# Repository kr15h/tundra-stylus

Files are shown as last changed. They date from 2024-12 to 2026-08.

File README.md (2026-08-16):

# Tundra Stylus

> This project has migrated. See [Lighthouse Stylus](https://gitlab.com/kriwkrow/lighthouse-stylus).

Tundra Tracker stylus baseplate for 3D positional tracking. This repository contains design files and test application source code. It currently works with [SteamVR](https://store.steampowered.com/app/250820/SteamVR/), but [libsurvive](https://github.com/cntools/libsurvive) support is on its way.

https://github.com/user-attachments/assets/fd64adfa-e3c0-4b6a-a956-ca7f262a2909

## Introduction

Vive Lighthouse system is great! The main use of it is VR, but what about drawing or painting in space? Stylus input is the natural choice of many, but there is no VIVE Lighthouse Stylus available. Logitech almost launched VR Ink, but then decided not to. What to do?

[Tundra Tracker](https://tundra-labs.com/products/additional-tracker) is the smallest available off-the-shelve tracker that is compatible with the VIVE Lighthouse system. It offers a great deal of flexibility via its [IO Expansion Board](https://tundra-labs.com/products/tundra-tracker-io-expansion-board). With that in mind, all we need is a neat circuit board with buttons and a 3D-printable structure that looks and feels like a stylus. 

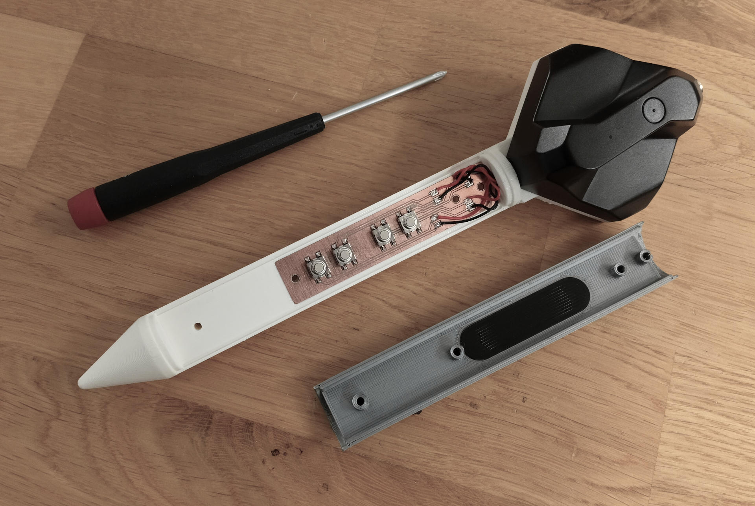
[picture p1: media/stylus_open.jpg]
Stylus Open


And that is Tundra Stylus! Produce the circuit board, 3D print the enclosure and you are ready to go, given that you have the Tundra Tracker and its IO Expansion board.

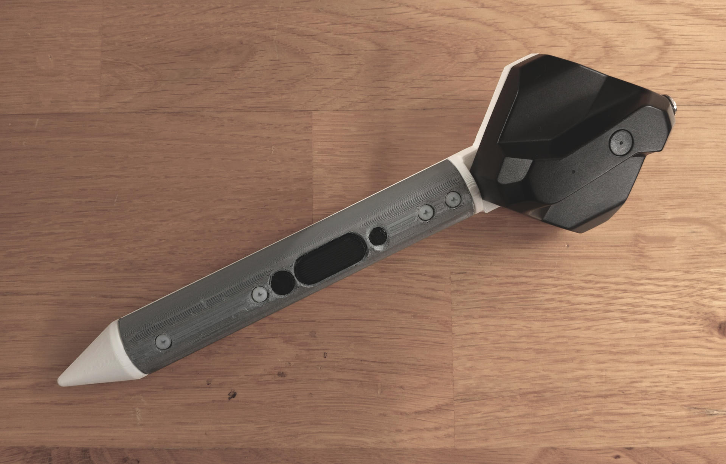
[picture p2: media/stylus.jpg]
Stylus


## Getting Started

Here is a table of contents of different documentation sections that will tell you what to do. You can also jump right to the design, electronics and software sections if you know all that by heart and prefer not to read too much documentation. It is up to you.

- [BOM](docs/BOM.md)  
  Start here as you will need to purchase some things to get started.
- [PCB Production](docs/PCB_PRODUCTION.md)  
  This may take time too so better start early.
- [3D Printing](docs/3D_PRINTING.md)  
  This one is relatively fast, given you have FDM printer available.
- [Assembly](docs/ASSEMBLY.md)  
  Putting it all together should be not hard, given you have all the parts (and tools).
- [Usage](docs/USAGE.md)  
  The setup and software part of the process.
- [Contributing](docs/CONTRIBUTING.md)  
  You are willing to improve something? Great!

## License

This repository contains multiple components, each licensed under different terms. Please review the specific license for each component below.

1. The CAD files in this repository are licensed under the **Creative Commons Attribution-NonCommercial 4.0 International (CC BY-NC 4.0)**.
2. The electronics design files in this repository are licensed under the **Creative Commons Attribution-NonCommercial 4.0 International (CC BY-NC 4.0)**.
3. The source code in this repository is licensed under the **MIT License**.

Please consult [LICENSE.md](LICENSE.md) for more detail.

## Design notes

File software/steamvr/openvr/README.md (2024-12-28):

# SteamVR OpenVR proxy

This proxy uses Python OpenVR bindings to extract tracking data from SteamVR.

## Dependencies

- [SteamVR](https://store.steampowered.com/app/250820/SteamVR/) with null driver enabled
- [websocketd](http://websocketd.com/)
- [Python 3.6](https://www.python.org/) with [openvr](https://github.com/cmbruns/pyopenvr?tab=readme-ov-file)

## Usage

Make sure you start SteamVR and that the Tundra Tracker attached to the stylus is detected. The following will make the websocket server available at `ws://localhost:8080/`.

```
websocketd --address=localhost --port=8080 python proxy.py
```

If you want to debug, you probably would like to enable verbose output.

```
python proxy.py -v
```

You can also display help if you want.

```
python proxy.py -h
```

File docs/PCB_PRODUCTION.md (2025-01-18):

# PCB Production

An essential component of the Tundra Stylus is its button board with 4 tactile switches. 

Tundra Stylus PCB

There are four cable pairs connecting the pads on the board with the Tundra Stylus IO Expansion board that is placed under the Tundra Stylus itself.

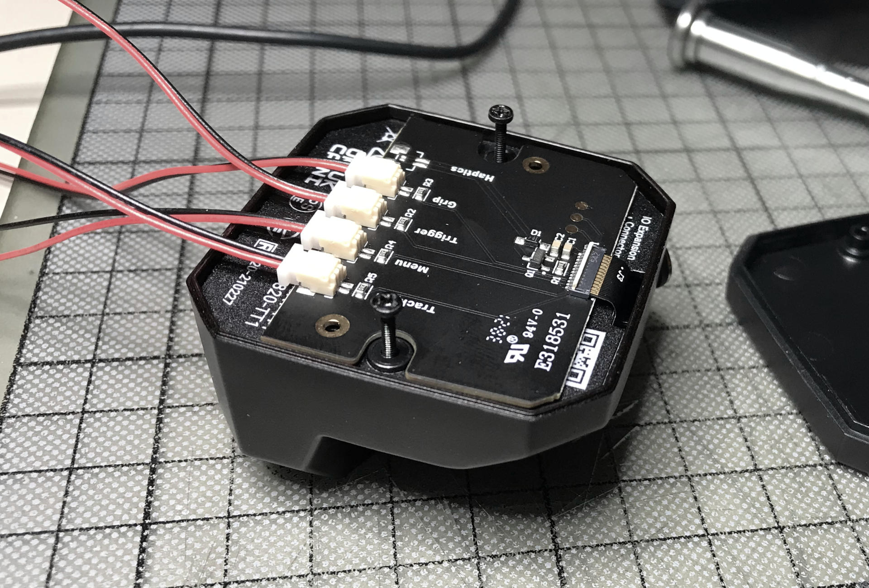
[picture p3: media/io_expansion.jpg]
IO Expansion Board


The cables are connected to the PCB in the following order (starting from the tip of the stylus upward).

1. Trigger
2. Grip
3. Trackpad
4. Menu

The names of the buttons might make you think that some of them can sense pressure, but all of them are plain digital IO buttons. You will need to cut them shorter, but try to leave a bit of extra in case you mess something up.

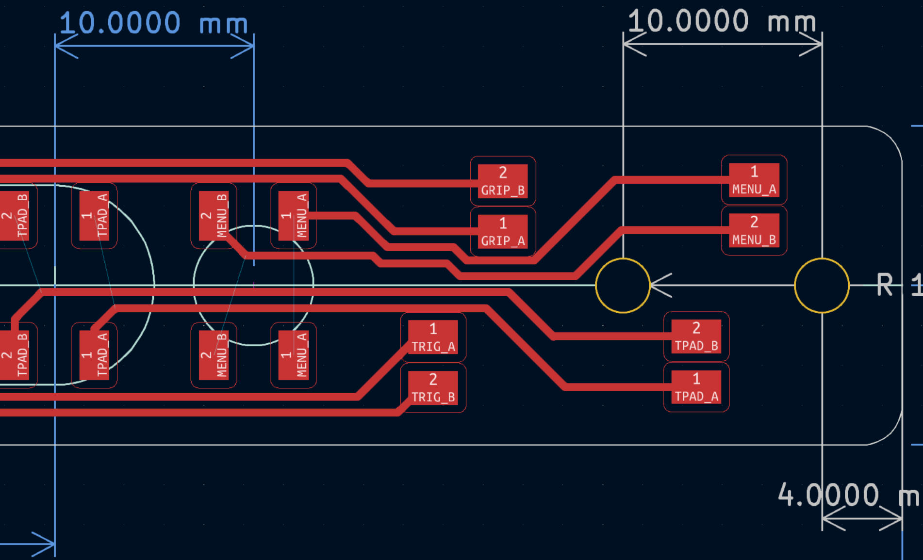
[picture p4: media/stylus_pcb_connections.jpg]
Stylus PCB Connections


## Making the Board

There are two ways to make the board.

1. PCB milling
2. Manufacturing online

### PCB Milling

Gerber files for PCB milling process can be found in [electronics/gerbers/milling](../electronics/gerbers/milling) directory. You can use KiCad electronics design software to export Gerber files for manufacturing online. KiCad 7 was used to design the board.

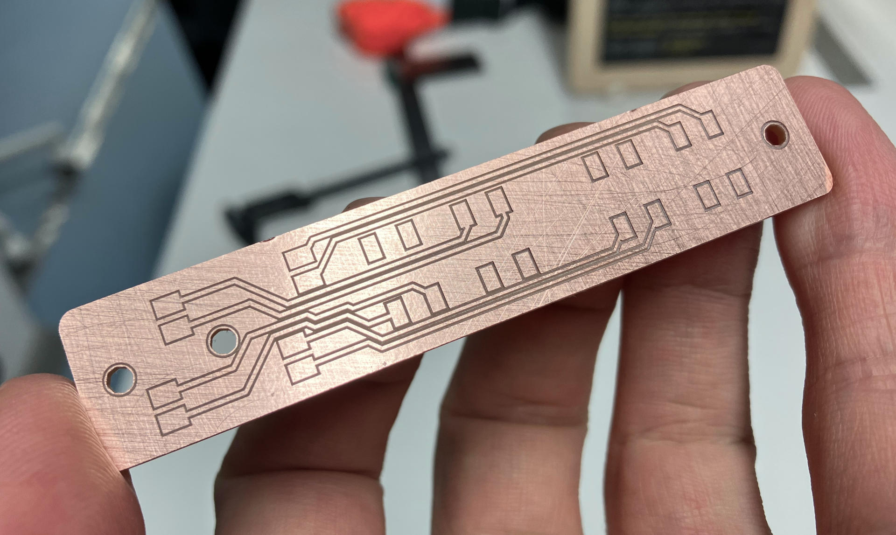
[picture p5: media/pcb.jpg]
Plain PCB


As for the milling process, CopperCAM software was used to calculate toolpaths in HPGL form. Then, Bungard CCD/2 MTC machine was used to mill the board. A 60deg V bit was used for isolation milling and a 0.8mm cylindrical tool was used to cut the holes and outline. FR2 single-sided copper clads from Bungard were used as the base material. 

### Manufacturing Online

Gerber files for manufacturing a single-sided board online is included in [electronics/gerbers/online](../electronics/gerbers/online). It has been tested with JLCPCB and PCBWay. It should show up as in the images below. 

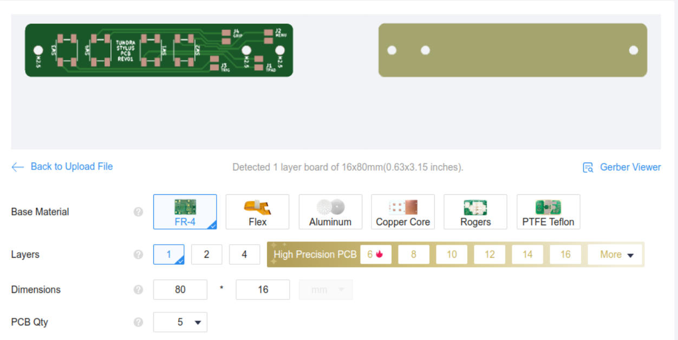
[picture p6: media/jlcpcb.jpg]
JLCPCB


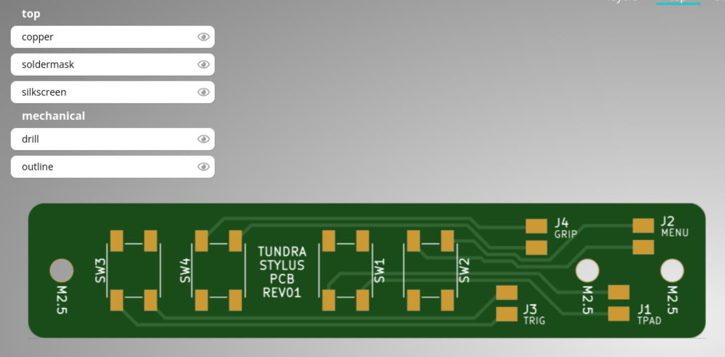
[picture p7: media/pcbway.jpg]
PcbWAY


As for the parameters, the following are most important.

| Parameter | Value |
| --- | --- |
| Base Material | FR-4 |
| Layers | 1 |
| PCB Thickness | 1.6mm |

Do not forget to order a SMT-Stencil if you want to use solder paste and reflow soldering. 

Below is a photo of how the board should look like when ordered via JLCPCB.

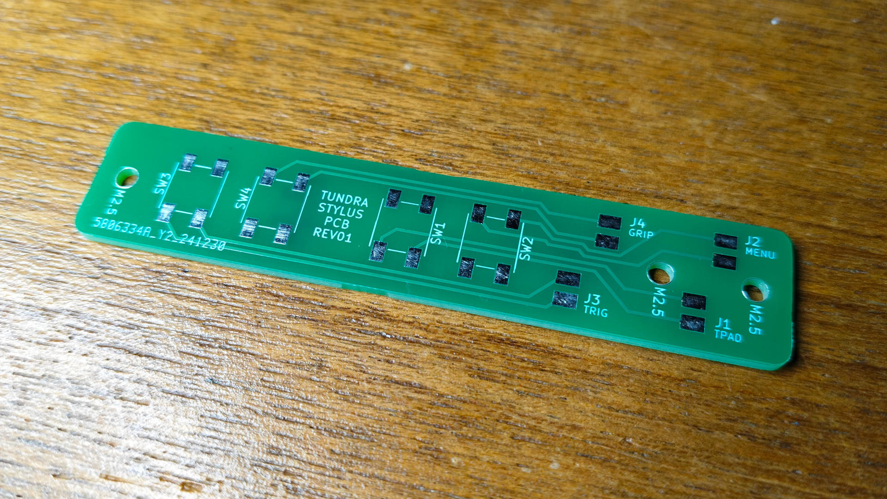
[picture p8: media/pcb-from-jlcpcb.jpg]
Photo of Tundra Stylus PCB from JLCPCB


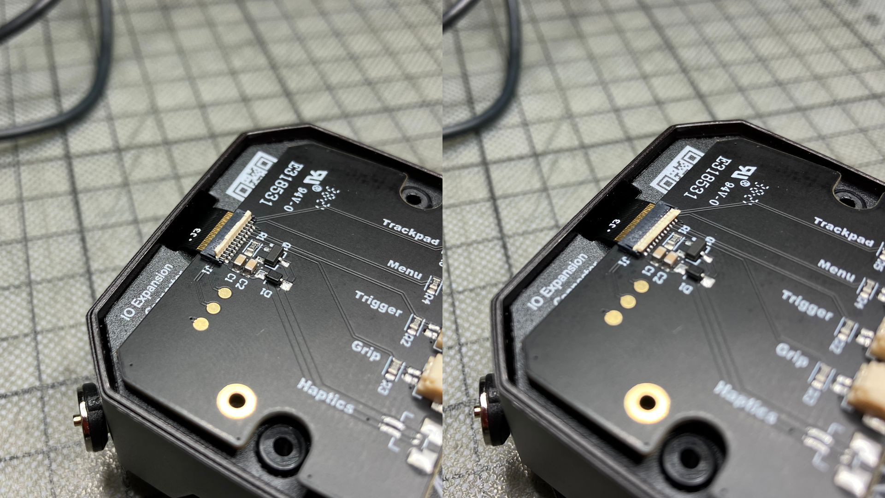
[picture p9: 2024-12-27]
media/tundra-io-ribbon.jpg

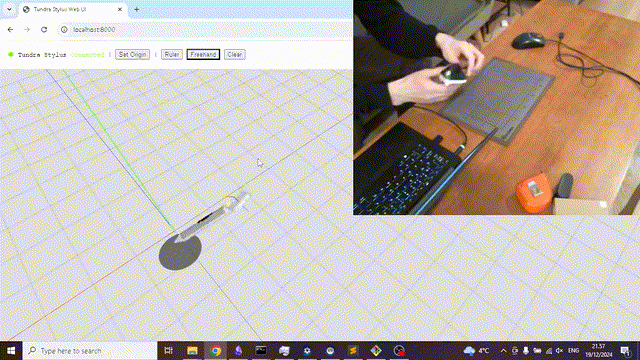
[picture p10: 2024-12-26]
media/hello.gif

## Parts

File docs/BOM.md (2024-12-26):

# BOM

Tundra Stylus would not be possible without a list of core off-the-shelve components. 

- [Tundra Tracker](https://tundra-labs.com/products/additional-tracker)
- [Tundra Tracker IO Expansion Board](https://tundra-labs.com/products/tundra-tracker-io-expansion-board)
- [VIVE Base Station](https://www.vive.com/us/accessory/base-station2/) (2pcs is optimal, but you can get up to 4 for ultra fidelity tracking)

## Tools

- 3D printer. I used Prusa MK4.
- PCB milling machine. I used Bungard CCD/2 MTC.
- Soldering station.
- Screwdriver.

## Parts

| Description | Amount | Link |
| --- | --- | --- |
| PLA Filament[^1] | 320g[^2] | [3DK Berlin](https://3dk.berlin/en/pla/109-pla-filament-milky-white.html) |
| FR2 single-sided copper clad at least 100x20mm[^3] | 1pcs | [Bungard](https://www.bungard.de/en/consumables/consumables/special-purpose-laminates)[^4] |
| Nylon bolts, M2.5, 20mm | 4pcs | [DigiKey](https://www.digikey.fi/en/products/detail/essentra-components/50M025045D020/11637988) |
| Nylon Nuts, M2.5 | 4pcs | [DigiKey](https://www.digikey.fi/en/products/detail/essentra-components/04M025045HN/9677099) |
| Tactile switch, Omron, B3SN-3112P | 4pcs | [DigiKey](https://www.digikey.com/en/products/detail/omron-electronics-inc-emc-div/B3SN-3112P/27856) |

[^1]: It is up to you what PLA type and manufacturer you choose. I printed with filament from 3dk.berlin on Prusa MK4 printers at the Aalto Fablab.

[^2]: The weight here is the avaiable spool size as it would be probably hard to purchase an exact amount.

[^3]: This is if you choose to do PCB milling at a fablab. Of course you can use FR4, but it is at your own risk. 

[^4]: Bungard is the manuacturer and you should contact them to find out distributors in your country.

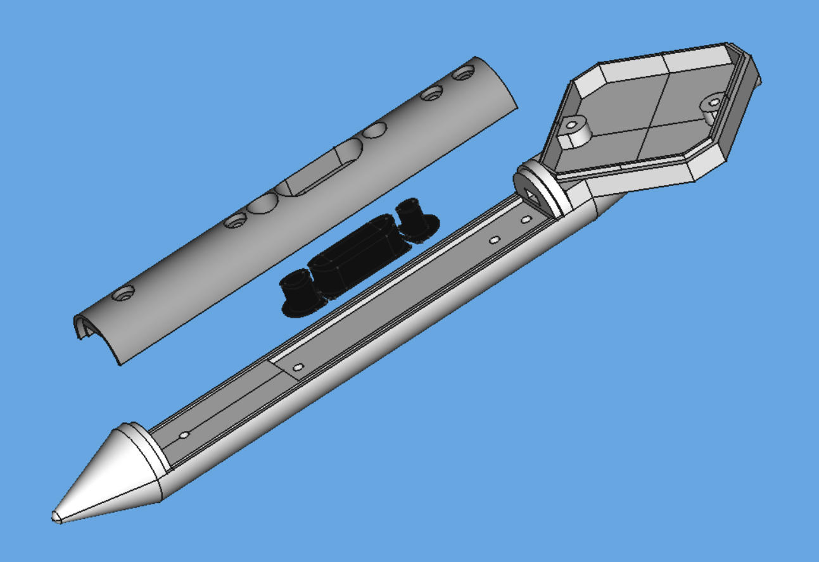
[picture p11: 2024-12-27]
media/design_parts.jpg

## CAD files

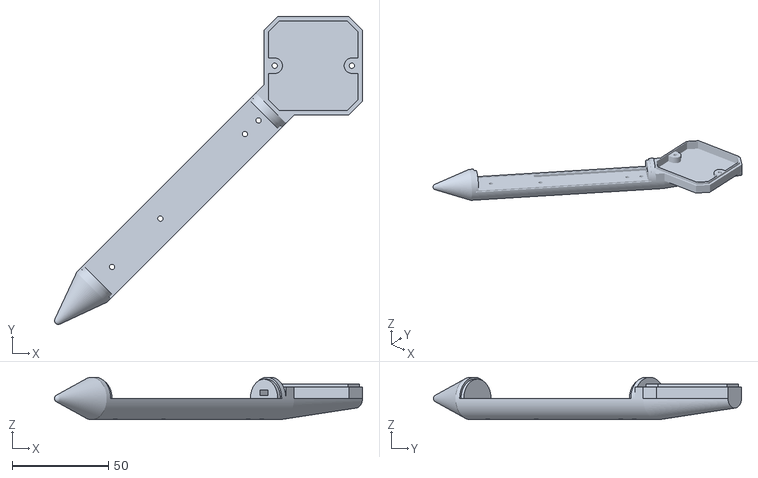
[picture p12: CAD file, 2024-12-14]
design/3dprint/TundraStylus_Rev01-Baseplate.stl
159.6 x 159.6 x 22.0

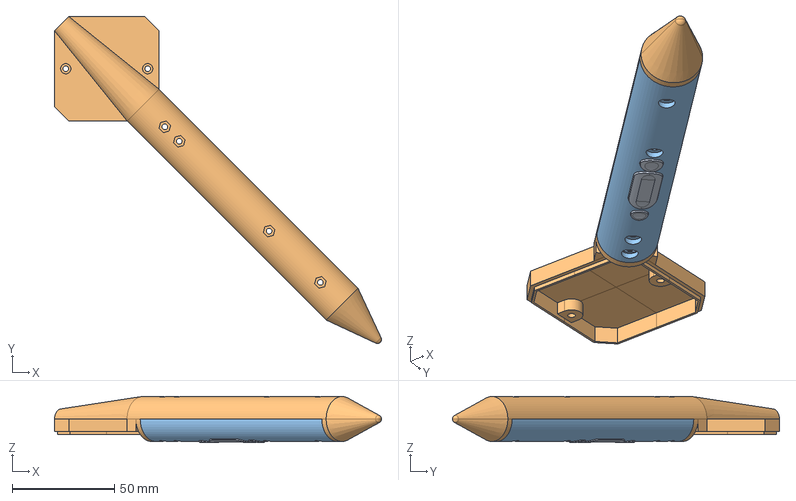
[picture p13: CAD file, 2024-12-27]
design/freecad/TundraStylus_Rev01.FCStd
159.6 x 159.6 x 22.5 mm
ButtonInlay
Baseplate
Cover

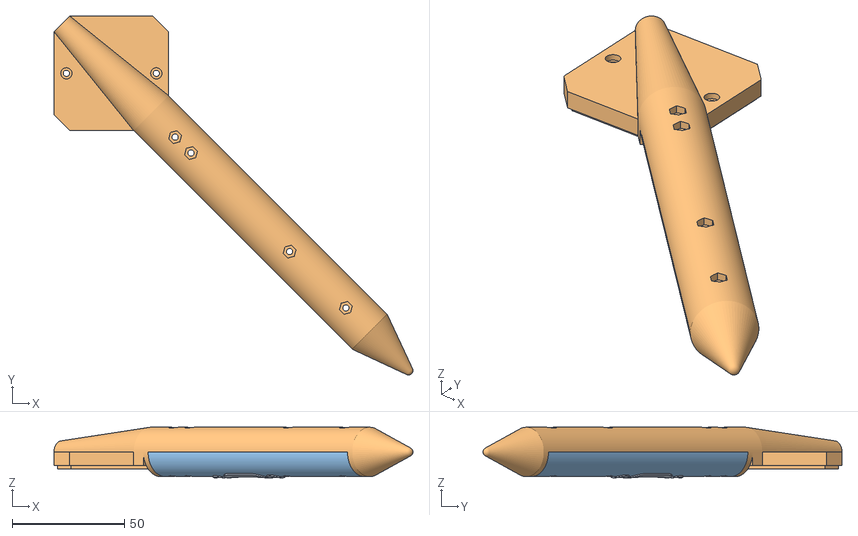
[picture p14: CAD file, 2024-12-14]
software/webui/assets/models/tundrastylus.obj
159.6 x 159.6 x 22.5
Buttons Final
Base Final
Cover Final

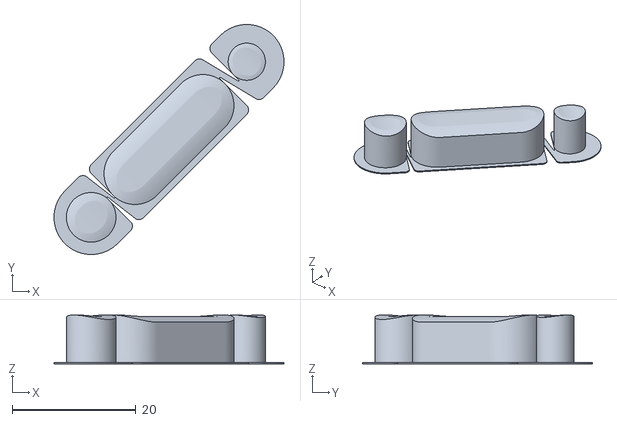
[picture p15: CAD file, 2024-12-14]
design/3dprint/TundraStylus_Rev01-ButtonInlay.stl
37.1 x 37.1 x 7.90

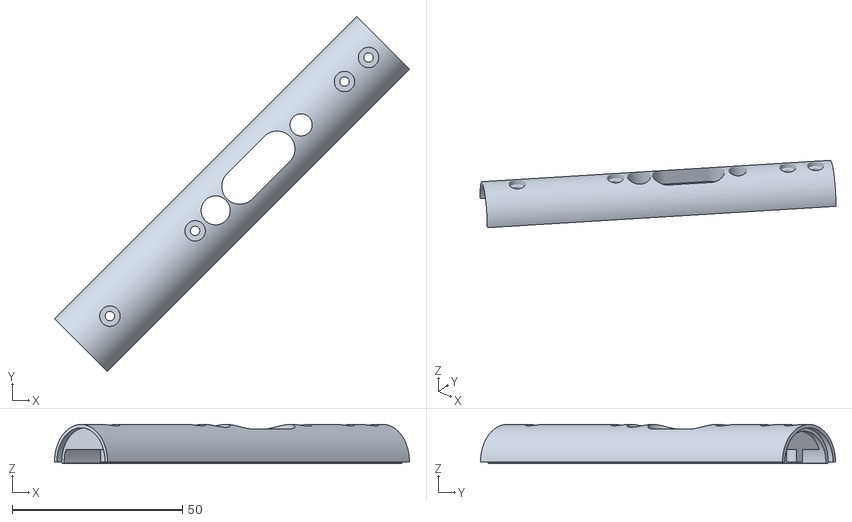
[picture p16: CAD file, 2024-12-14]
design/3dprint/TundraStylus_Rev01-Cover.stl
104.2 x 104.2 x 11.5

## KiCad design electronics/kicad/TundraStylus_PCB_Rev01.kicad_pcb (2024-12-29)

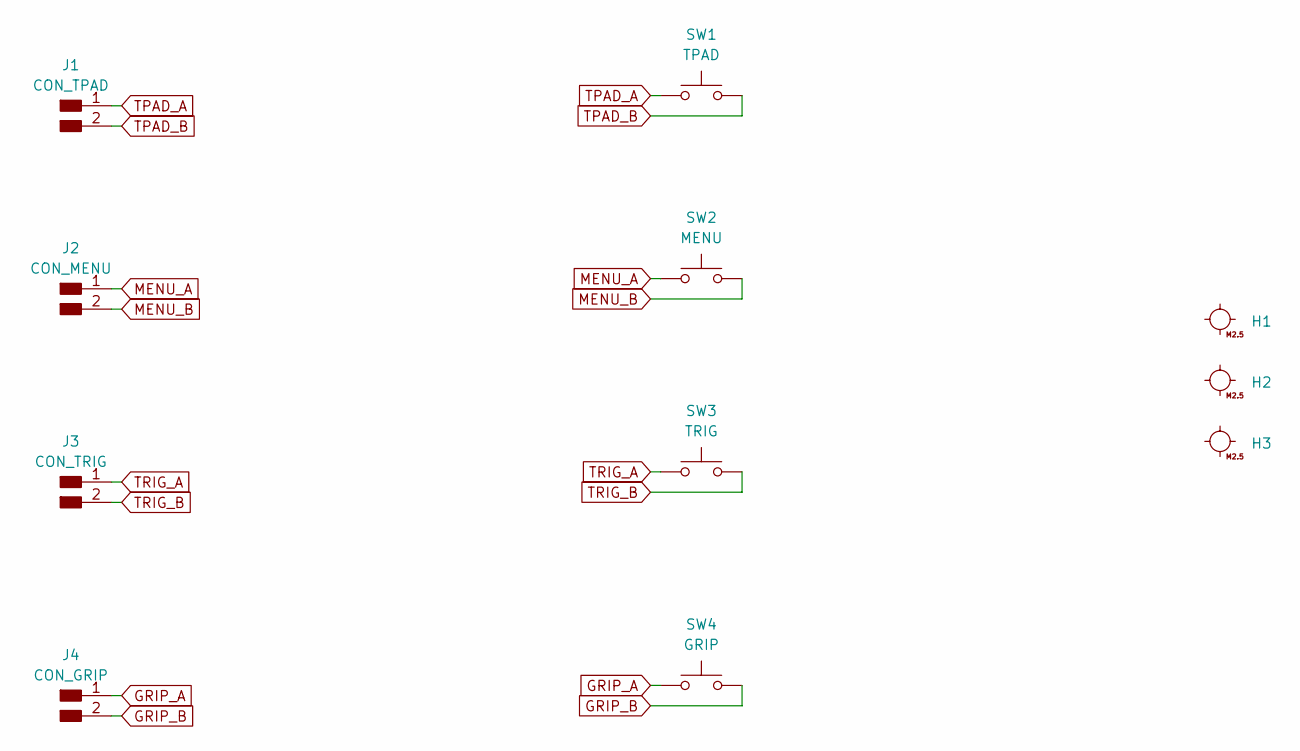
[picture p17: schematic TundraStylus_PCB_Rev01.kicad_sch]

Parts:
H1, H2, H3: MountingHole_M2.5
J1: CON_TPAD; PinHeader_1x02_P2.54mm_Horizontal_SMD
J2: CON_MENU; PinHeader_1x02_P2.54mm_Horizontal_SMD
J3: CON_TRIG; PinHeader_1x02_P2.54mm_Horizontal_SMD
J4: CON_GRIP; PinHeader_1x02_P2.54mm_Horizontal_SMD
SW1: TPAD; Button_Omron_B3SN_6.0x6.0mm
SW2: MENU; Button_Omron_B3SN_6.0x6.0mm
SW3: TRIG; Button_Omron_B3SN_6.0x6.0mm
SW4: GRIP; Button_Omron_B3SN_6.0x6.0mm

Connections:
GRIP_A: J4.1, SW4.1
GRIP_B: J4.2, SW4.2
MENU_A: J2.1, SW2.1
MENU_B: J2.2, SW2.2
TPAD_A: J1.1, SW1.1
TPAD_B: J1.2, SW1.2
TRIG_A: J3.1, SW3.1
TRIG_B: J3.2, SW3.2

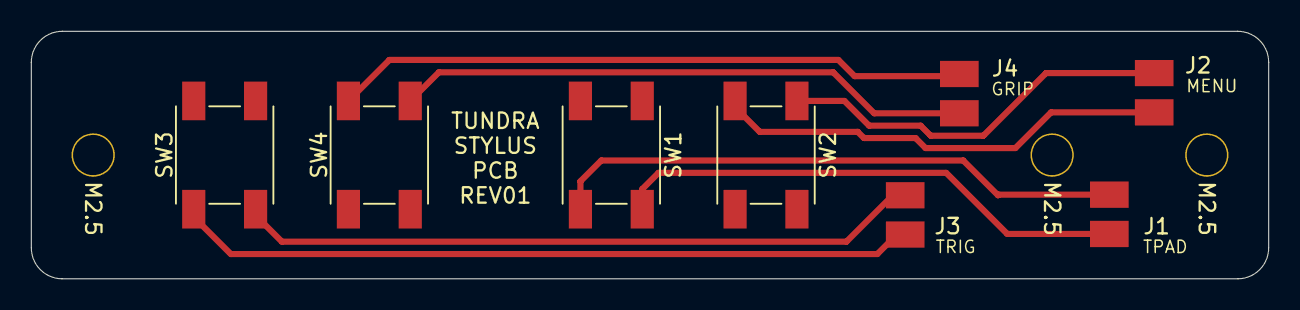
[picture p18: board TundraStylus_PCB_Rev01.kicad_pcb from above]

Board: 2 copper layers, 80.0 x 16.0 mm, 11 parts (0 on the bottom side), 8 nets.

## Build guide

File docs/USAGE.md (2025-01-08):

# Usage

Now when you have the Tundra Stylus assembled, it is time to make sure it works. You will need to set up your physical space for that first. Also make sure that your Tundra Tracker is fully charged.

## Setting up Base Stations

Tundra Stylus has been tested with Vive Base Station 2.0. One is enough, but if you want to use two or more, make sure you change the channel for one of them as in order to take advantage of multi-base-station tracking, the base stations should be on different channels. You can do this by using a pin similar to one used to remove SIM from iPhone. There is a little pin-hole on the back of the Vive Base Station, insert the pin there and press until you feel/hear a click. The base station should show up with a different channel in SteamVR now.

It is recommended to set up the base stations higher above head level, in the corners of the room. The field of view of base stations is 120deg. Tilt them a bit downward so that they cover all areas the tracker is going to reside. Also take into account the body position of yours. Set the base stations up in a way so that it is less likely that your body is going to be in the way.

## Testing in SteamVR

Once the base stations are set up, fire up your Steam software and install SteamVR. I was testing it on Windows, and got half-way on Linux, but the main reason for that was the uneven way the null driver behaves on both of the systems. 

I am using the stylus without a headset to drive cursor on screen. In order to be able to use it without headset, you will need to enable the null driver.

First, edit the default Steam VR settings and enable the "null" driver. Open the following file in a text editor and set `"enable"` to `true`.

```
C:\Program Files (x86)\Steam\steamapps\common\SteamVR\drivers\null\resources\settings\default.vrsettings
```

```json
"enable": true
```

Then, proceed to the general SteamVR settings.

```
C:\Program Files (x86)\Steam\steamapps\common\SteamVR\resources\settings\      
default.vrsettings
```

```json
"requireHmd": false,
"forcedDriver": "null",    
"activateMultipleDrivers": true
```

Restart SteamVR and turn on the tracker on the stylus. Make sure the tracker dongle included with Tundra Tracker is plugged into your computer, the VIVE base stations, and the Tundra Tracker are on. Wait for the base stations and tracker icons to show up. 

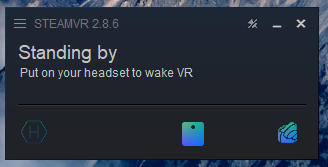
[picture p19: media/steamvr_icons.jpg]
SteamVR Icons


Next, configure your tracker as a handheld controller.

1. Select the SteamVR menu and go to Settings
2. Select Controllers
3. Select Manage Trackers
4. Set Tracker Role as Held in Hand
5. Set to Any hand (default)

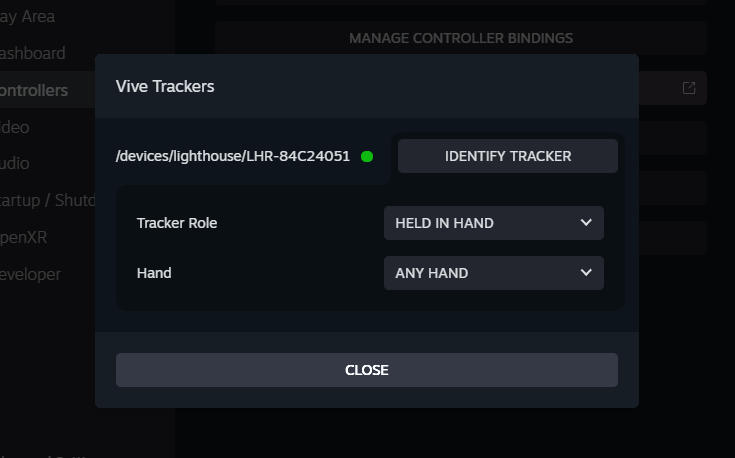
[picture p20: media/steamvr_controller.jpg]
SteamVR Controller Settings


Then open the test controller panel and test the controller.

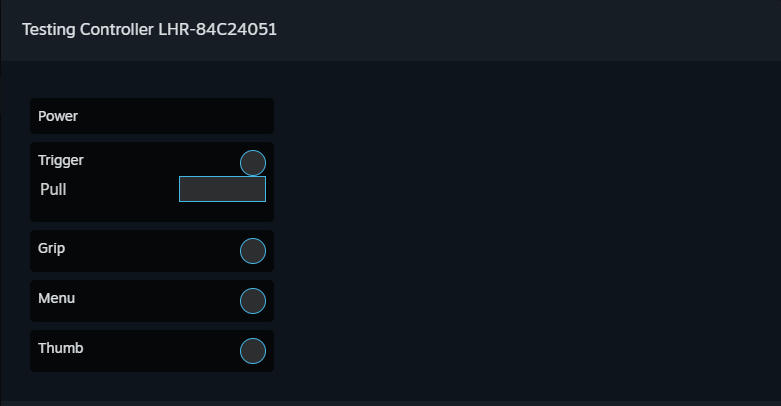
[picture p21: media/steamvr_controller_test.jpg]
SteamVR Test Controller


The circles should appear as filled as soon as you press buttons on the stylus.

https://github.com/user-attachments/assets/c7b850f1-a4ad-4b7b-adab-196a3f2940df

On Windows, you should also be able to see the Tundra Tracker floating in space via the VR View.

## Testing with Web UI

Now, that SteamVR can recognize the tracker, we can move on to application-specific adventures. The repository includes middleware, a proxy application that uses OpenVR API to communicate with SteamVR and extracts pose information that can then be passed on to any application on your computer. 

### Proxy

You can find the SteamVR compatible OpenVR proxy in the [software/steamvr](../software/steamvr/) directory. There is a README file that explains prerequisites and launching sequence. 

### Web UI

Once you get it to run, proceed to the Web UI. It is build using threejs 3D library and JavaScript modules. It requires to be launched via a local webserver. Instructions can be found in the [software/webui](../software/webui/) directory.

Open the browser and go to the address you configure your local webserver with. It will take some time for the application to start receiving tracker pose information, thus the "Waiting for Stylus" message will be there for some seconds. Once the tracker starts sending pose information, you can do several things.

1. Use the Menu button to set the origin
2. Use the Mouse to select one of two test tools
    1. Ruler tool
    2. Freehand tool
3. Use the Trigger button to place points in the case of the Ruler tool or start drawing a line with the Freehand tool.

https://github.com/user-attachments/assets/fd64adfa-e3c0-4b6a-a956-ca7f262a2909

## Creating your Own App

To build your own JavaScript application, you can reuse the `TundaStylus` class that can be found in [software/webui/js](../software/webui/js/TundraStylus.js). It follows a three step initialization.

```
// Step 1: Create sylus manager instance
const stylus = new TundraStylus();

// Step 2: Add listeners
stylus.addEventListener('new_stylus', event => { ... });
stylus.addEventListener('pose',       event => { ... });
stylus.addEventListener('click',      event => { ... });
stylus.addEventListener('pressed',    event => { ... });
stylus.addEventListener('released',   event => { ... });

// Step 3: Connect to WebSocket host
stylus.connect('ws://localhost:8080');
```

The `TundraStylus` class extends the built-in [CustomEvent](https://developer.mozilla.org/en-US/docs/Web/API/CustomEvent/CustomEvent) class. It carries data that can be accessed via `event.detail` member variable.

THe `TundraStylus` can capture and forward data of multiple styluses. As soon as first message with a specific controller ID is received, a `new_stylus` event is emited. 

The `new_stylus` event carries the ID of the newly added stylus.

```
{
    id: 1
}
```

The `pose` event carries the raw pose of the tracker, as well as the calculated tip position as `event.detail.position`.

```
{
    id,
    position,
    tracker: {
        pose,
        position,
        quaternion
    }
}
```

The `click`, `pressed` and `released` events also have a `buttonName` variable that can be one of four values: `trig`, `menu`, `grip` or `tpad`. 

```
{
    id,
    buttonName: "trig | menu | grip | tpad",
    position,
    tracker: {
        pose,
        position,
        quaternion
    }
}
```

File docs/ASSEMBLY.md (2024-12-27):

# Assembly

Given that you have soldered the tactile switches to the button PCB and processed the 3D printed parts, you are ready to proceed with the assembly process.

You will need to shorten the cables that come with the Tundra Tracker IO Expansion Board. To do that, start with connecting the cables to the expansion board. Then, open up the Tundra Tracker and insert the IO board like so.

IO Board Insertion

There are the 2x Torx T5 Thread Forming M1.6 screws missing in the image. I lost them somewhere, that is why they are not there. 

> The flat cable connector on the right has a lock mechanism. Make sure you insert the cable properly and then use a small instrument, such as tweezers, to lock it.

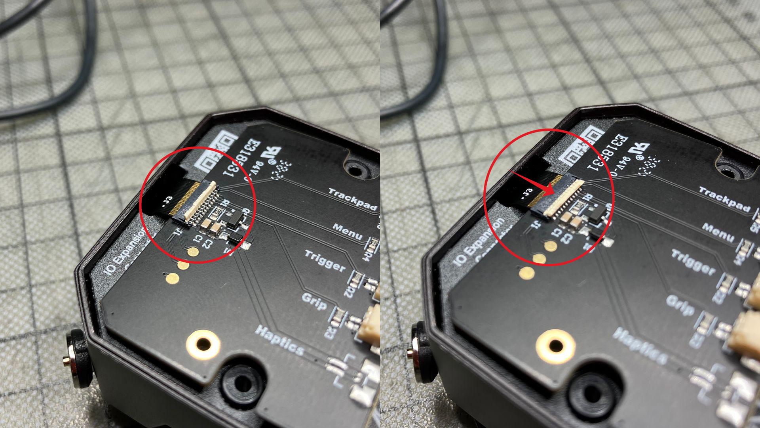
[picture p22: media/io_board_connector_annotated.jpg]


Use paper tape and label the cables as you won't be able to trace them back to the connectors on the IO board once you attach the Tundra Tracker to the Baseplate.

Then, attach the Tundra Tracker to the stylus Baseplate using the same bolts that were used to attach the original Tundra Tracker baseplate.

Guide the cables through the hole in the back of the stylus baseplate and position the circuit board. Cut the cables one-by-one, strip them, and solder them to the respective pads of the buttons. 

Tundra Stylus w/o Cover

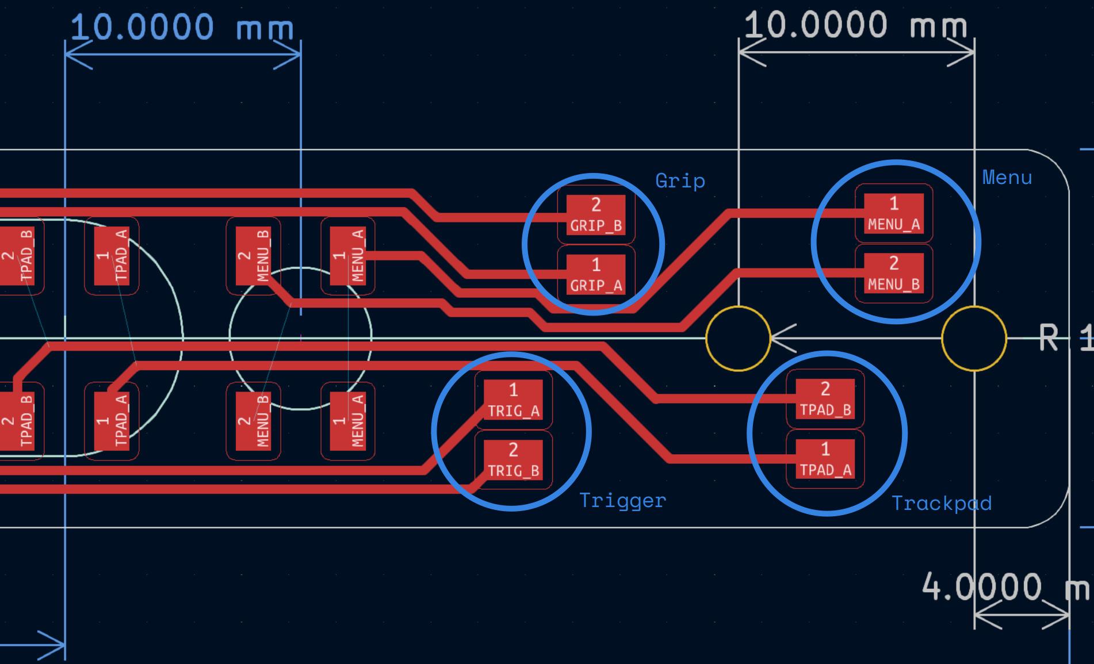
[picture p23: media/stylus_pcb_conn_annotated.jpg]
PCB button mapping


Finally, use the 4x Nylon bits and bolts to keep the cover in place. Press the hexagonal nylon nuts in their respective pockets on the outer wall of the stylus baseplate, insert the button inlay in the cover and close the whole structure. Use a screwdriver to fasten the 20mm bolts.

Final Assembly

At this point, you can move on to testing and using the stylus.

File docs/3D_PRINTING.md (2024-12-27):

# 3D Printing

There are three parts to be 3D printed.

1. The main stylus baseplate
2. Button inlay
3. Cover

3D models for all of them can be found in the [design/3dprint](../design/3dprint) directory. 

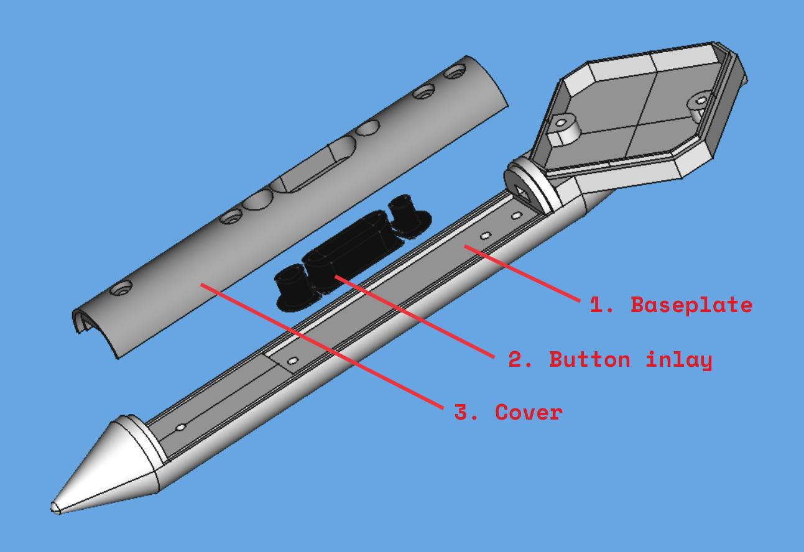
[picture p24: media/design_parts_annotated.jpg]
Design Parts


Prusa MK4 3D printers with PLA filament were used to print the parts. Material is not limited to PLA, it is up to you and your printing method. The models were sliced using the default 0.10mm FAST DETAIL preset with 20% infill and 0.4mm nozzle Input Shaper printer profile.

The baseplate and cover were printed inside-up to maintain precision in the inner part of thde design. This is to make sure that parts fit together without additional post-processing.

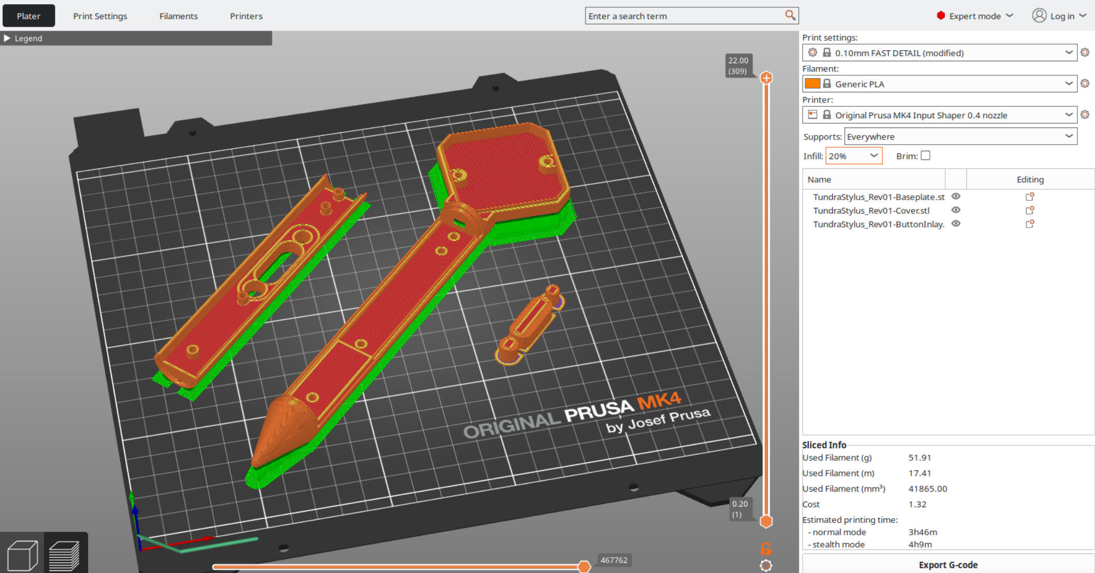
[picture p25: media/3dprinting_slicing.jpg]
Slicing


After printing, supports were removed and the surfaces processed with sanding paper. For better appearance, one could use medium-viscosity two-component epoxy glue, optional sanding, and spraypaint of your choice. 

## Design Adjustments

It is possible that some features do not work out as expected, due to shrinkage and other issues. No 3D printer is the same, but it is possible to adjust the design parameters of Tundra Stylus if needed.

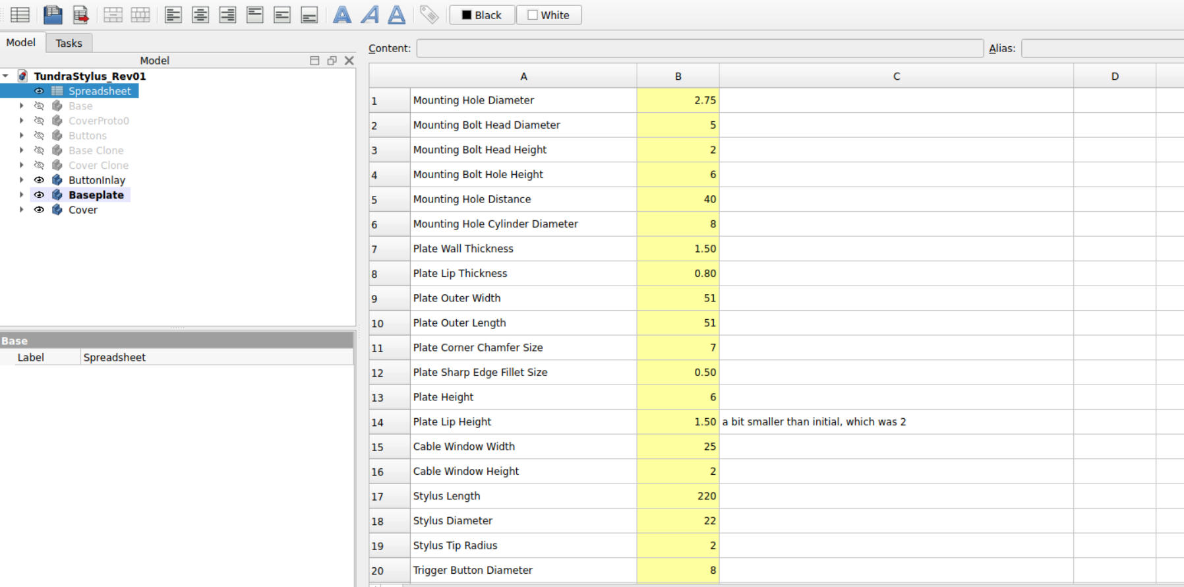
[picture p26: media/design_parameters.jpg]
Design Parameters in FreeCAD


Tundra Stylus enclosure design was made in FreeCAD 1.0. You can download and install it for free and it is compatible with all major operating systems. 

Once adjustments are made, you can export the Baseplate, ButtonInlay and Cover objects separately via File > Export.

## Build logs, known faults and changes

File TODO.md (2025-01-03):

# TODO

A shortlist of reminders what I wanted to do when I last touched the code.

- [ ] Remove threejs dependency from `TundraStylus` class
- [ ] Improve SteamVR setup guide
- [ ] libsurvive support

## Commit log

2024-12-14 Add webui until a point where we can test it with steam proxy
    [tundrastylus.obj]
2024-12-14 Add other files needed for replication
    [TundraStylus_Rev00_PCB.kicad_pcb, TundraStylus_Rev00_PCB.kicad_sch, TundraStylus_Rev01-Base Clone.stl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]
2024-12-14 Update model rotation
    [TundraStylus_Rev01.FCStd, tundrastylus.obj]
2024-12-15 Add button state sending to proxy and identify trigger button press and release in webui
2024-12-17 Add StylusManager and implement origin set on MENU button press
2024-12-17 Refactor a bit more so that the flow is more clear
2024-12-18 Add bare bones ruler tool that prints distance in console
2024-12-19 Limit framerate to 30 fps for now, performs better on my little computer
2024-12-26 Update BOM
2024-12-26 Bring tools up in BOM
2024-12-26 We need 4 bolts and nuts not just 3
2024-12-27 Update PCB production README
2024-12-27 Add unsaved changes to PCB production README
2024-12-27 Add 3D printing info to docs/3D_PRINTING.md
2024-12-27 Add detail to docs/3D_PRINTING.md
    [TundraStylus_Rev01-Baseplate.stl, TundraStylus_Rev01-ButtonInlay.stl, TundraStylus_Rev01-Cover.stl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]
2024-12-27 Populate docs/ASSEMBLY.md
2024-12-28 Add PCB manufacturing files for JLCPCB
    [TundraStylus_Rev00_PCB.kicad_pcb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]
2024-12-29 Update pcb files
    [TundraStylus_PCB_Rev01.kicad_pcb, TundraStylus_PCB_Rev01.kicad_sch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]
2025-01-18 Add photo of PCB from JLCPCB
